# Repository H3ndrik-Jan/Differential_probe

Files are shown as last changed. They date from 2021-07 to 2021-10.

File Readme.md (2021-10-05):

# Battery powered differential oscilloscope probe
This repository contains schematics and design files, simulations and measurement results of the probe.
More details: https://hackaday.io/project/181410-battery-powered-differential-probe
# Pictures
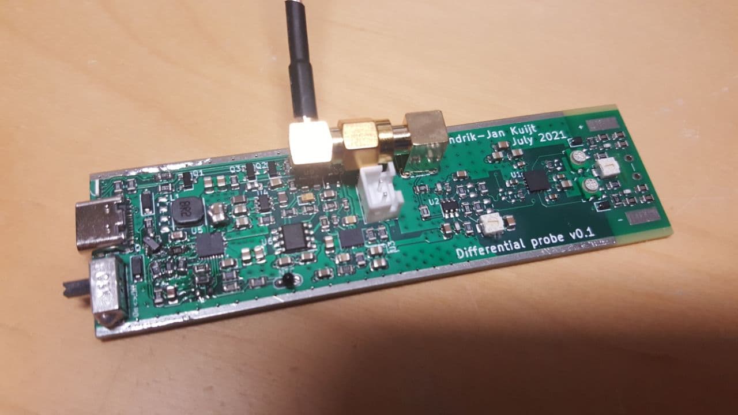
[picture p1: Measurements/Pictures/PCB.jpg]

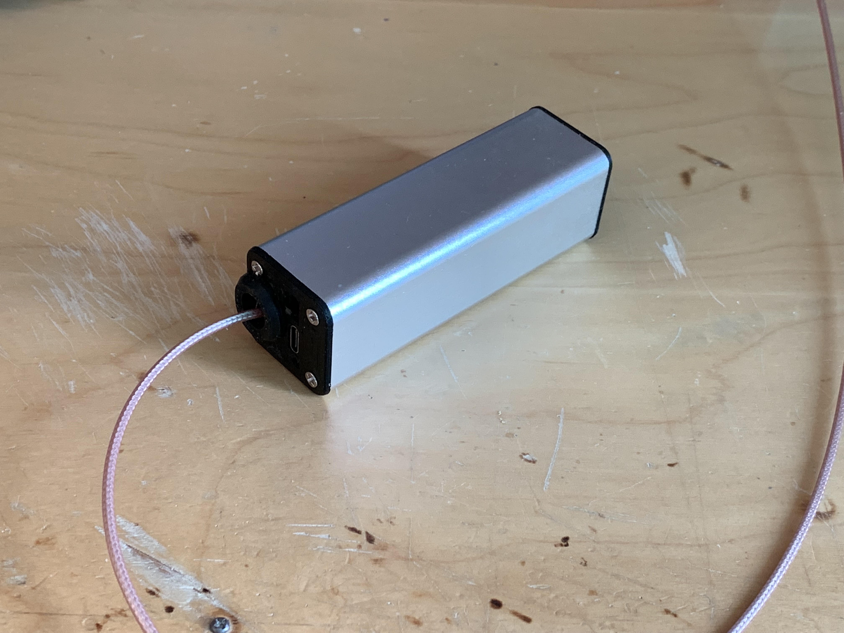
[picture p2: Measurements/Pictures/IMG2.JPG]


# 1Hz-950KHz transfer + THD:
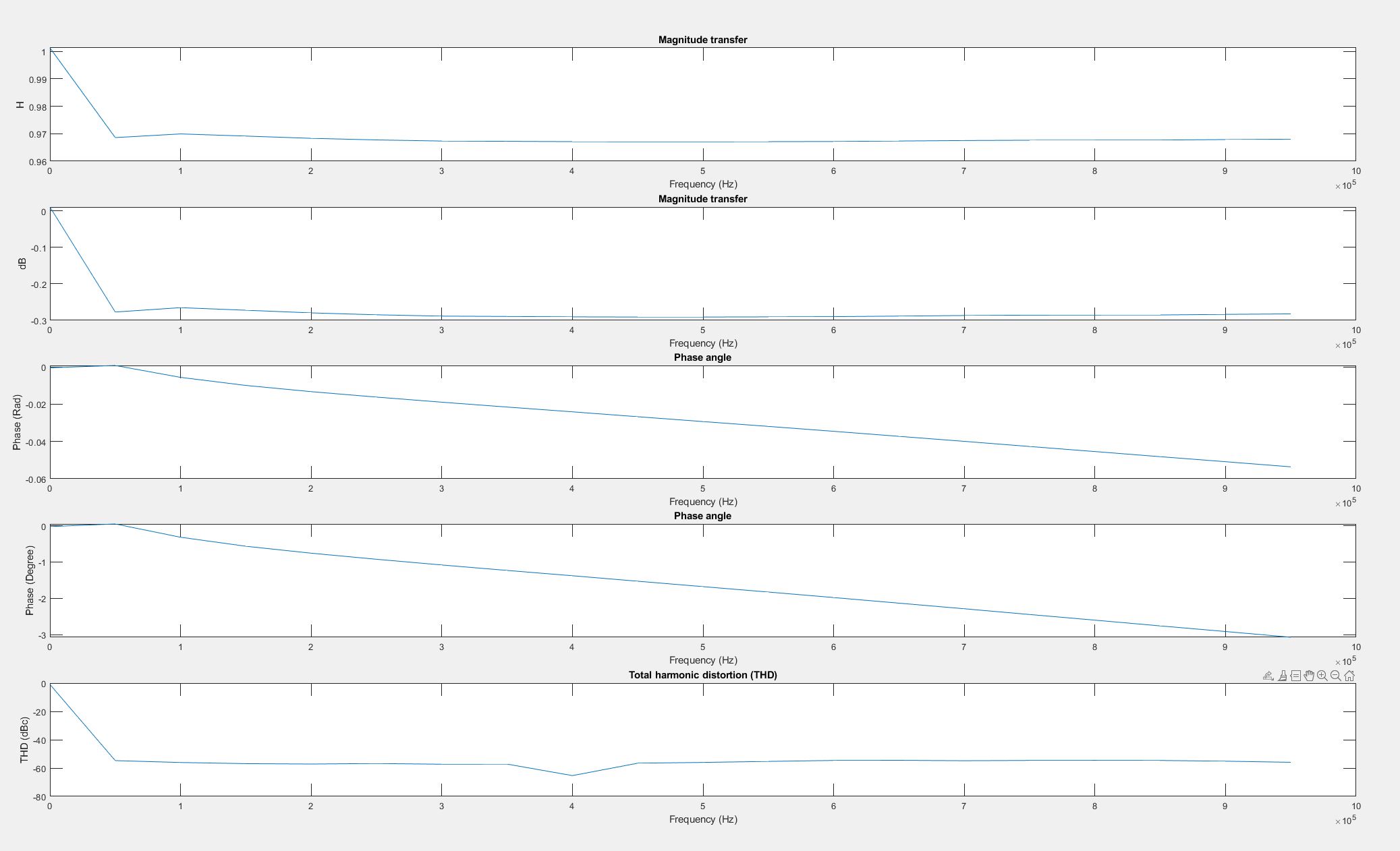
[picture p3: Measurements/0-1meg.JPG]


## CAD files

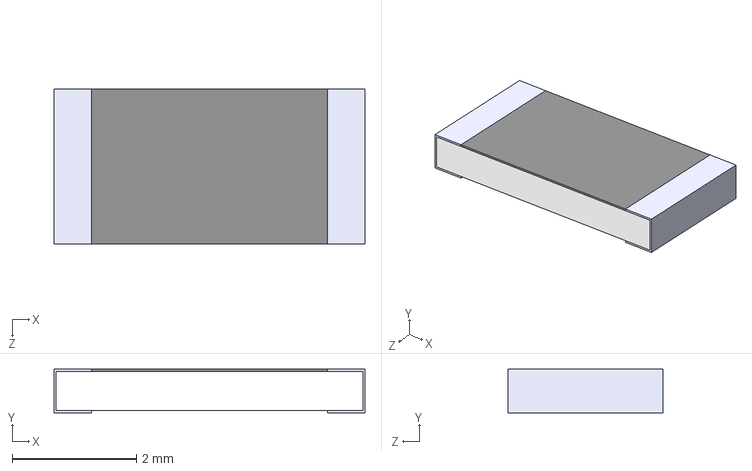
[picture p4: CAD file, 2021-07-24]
Diffprobe/3313J-1-103E.step
5.00 x 0.7 x 2.50 mm

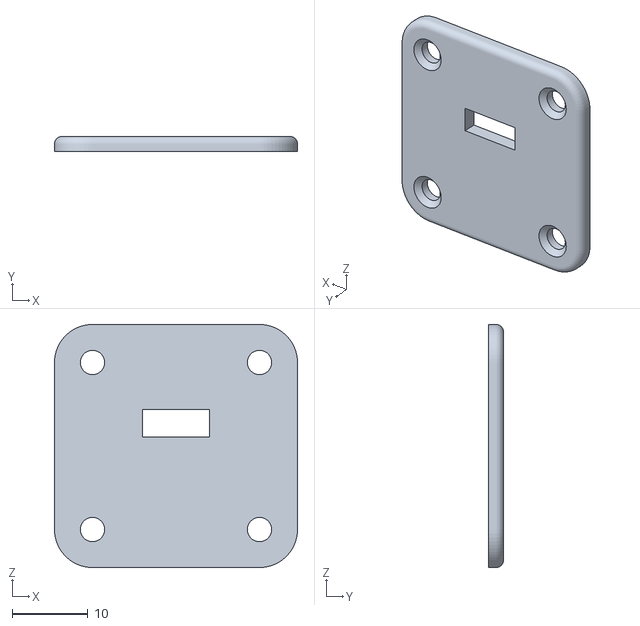
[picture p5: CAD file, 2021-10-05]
frontplate.stl
32.0 x 2.00 x 32.0

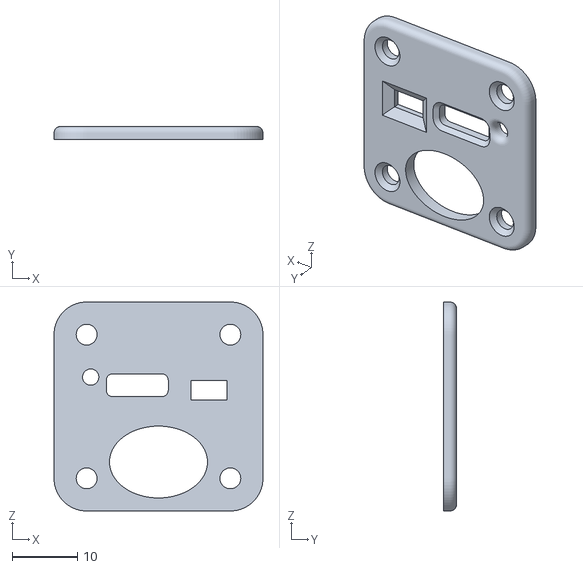
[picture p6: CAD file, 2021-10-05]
chargeplate.stl
32.0 x 2.00 x 32.0

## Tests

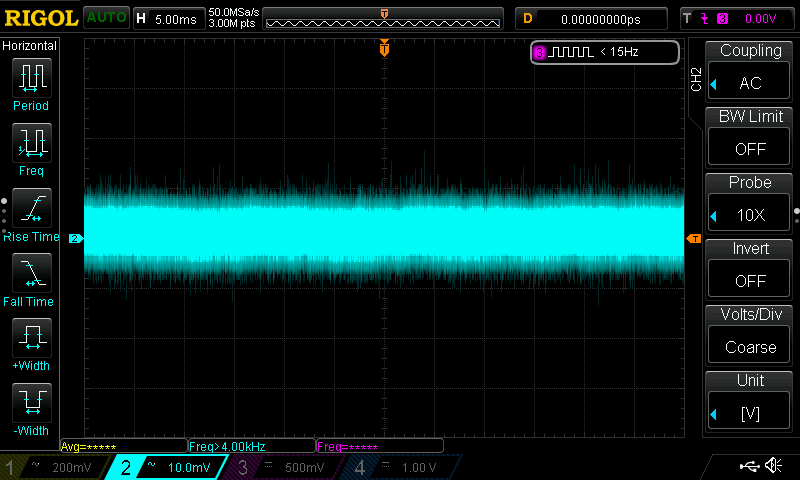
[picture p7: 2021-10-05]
Measurements/V+V-ripple5ms.png

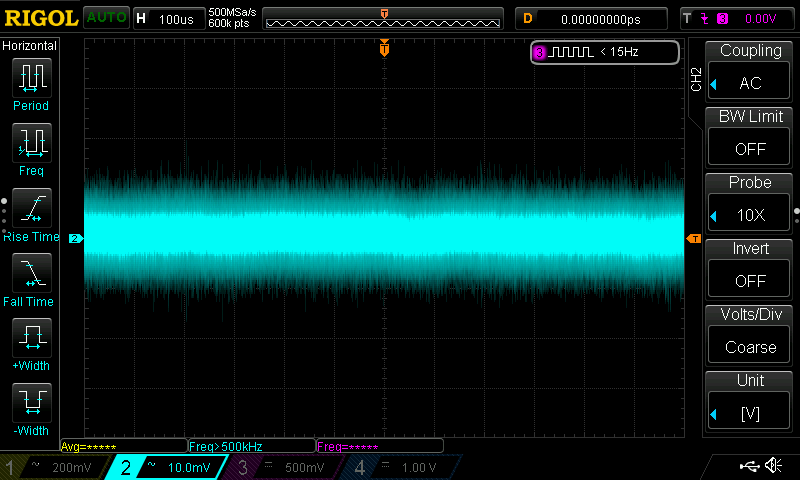
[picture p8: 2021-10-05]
Measurements/V+V-ripple100us.png

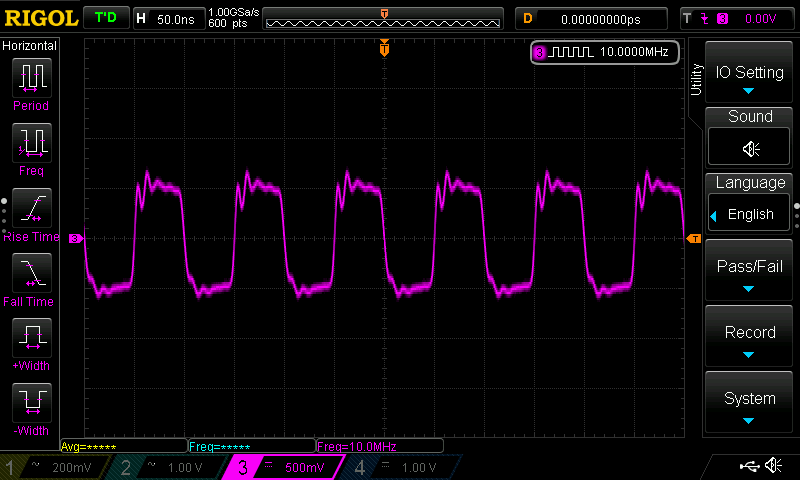
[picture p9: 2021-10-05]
Measurements/sqr10meg.png

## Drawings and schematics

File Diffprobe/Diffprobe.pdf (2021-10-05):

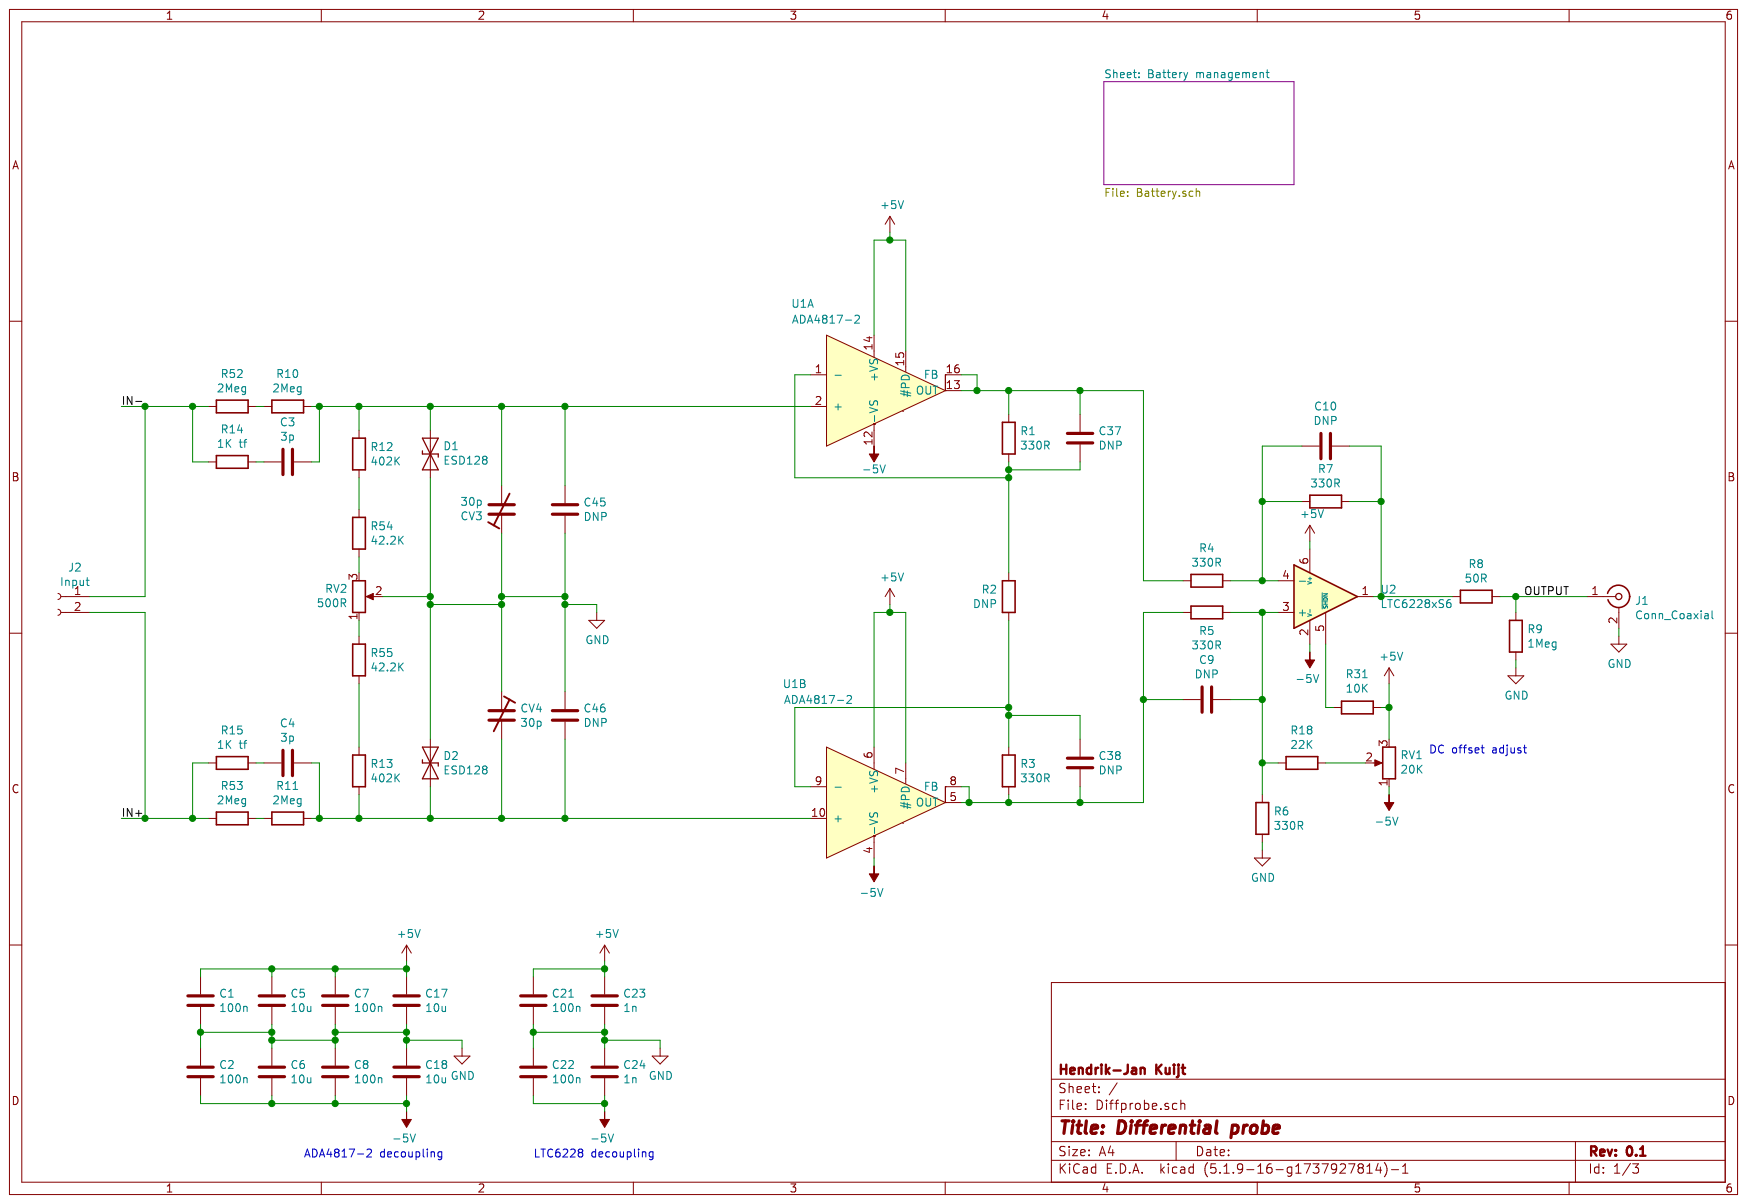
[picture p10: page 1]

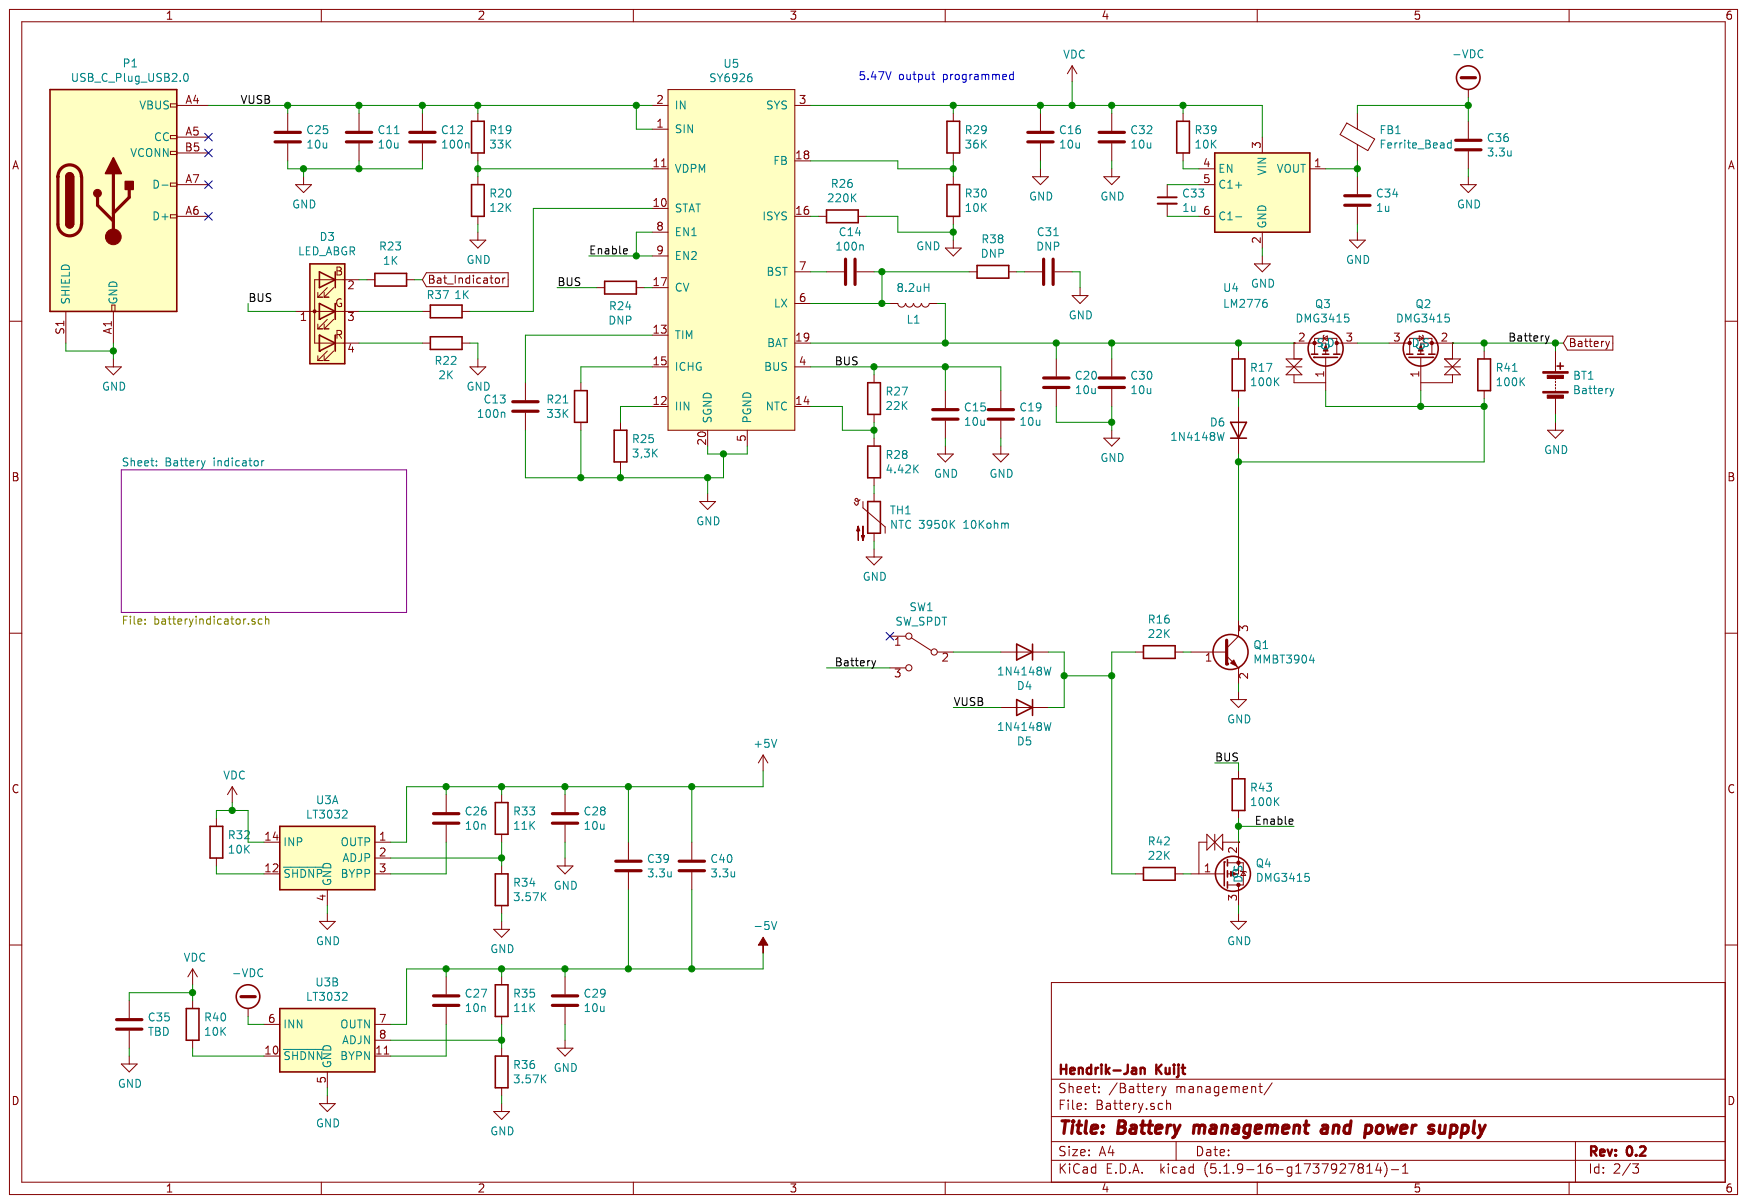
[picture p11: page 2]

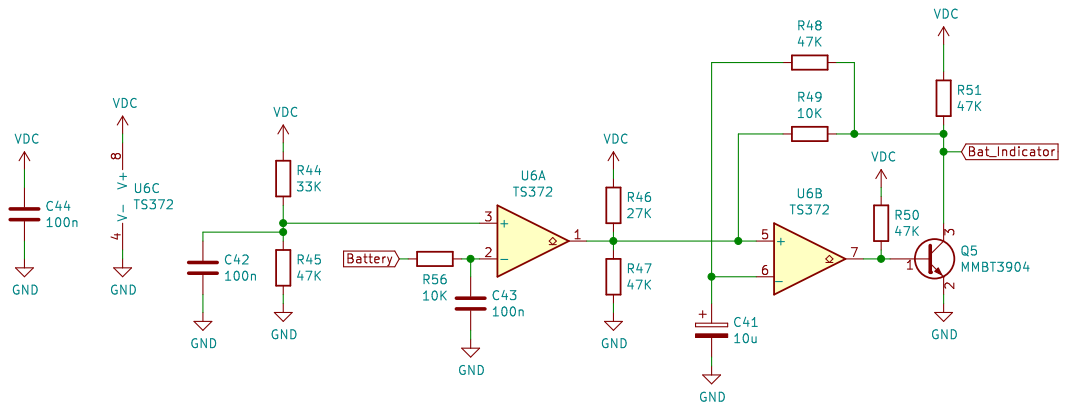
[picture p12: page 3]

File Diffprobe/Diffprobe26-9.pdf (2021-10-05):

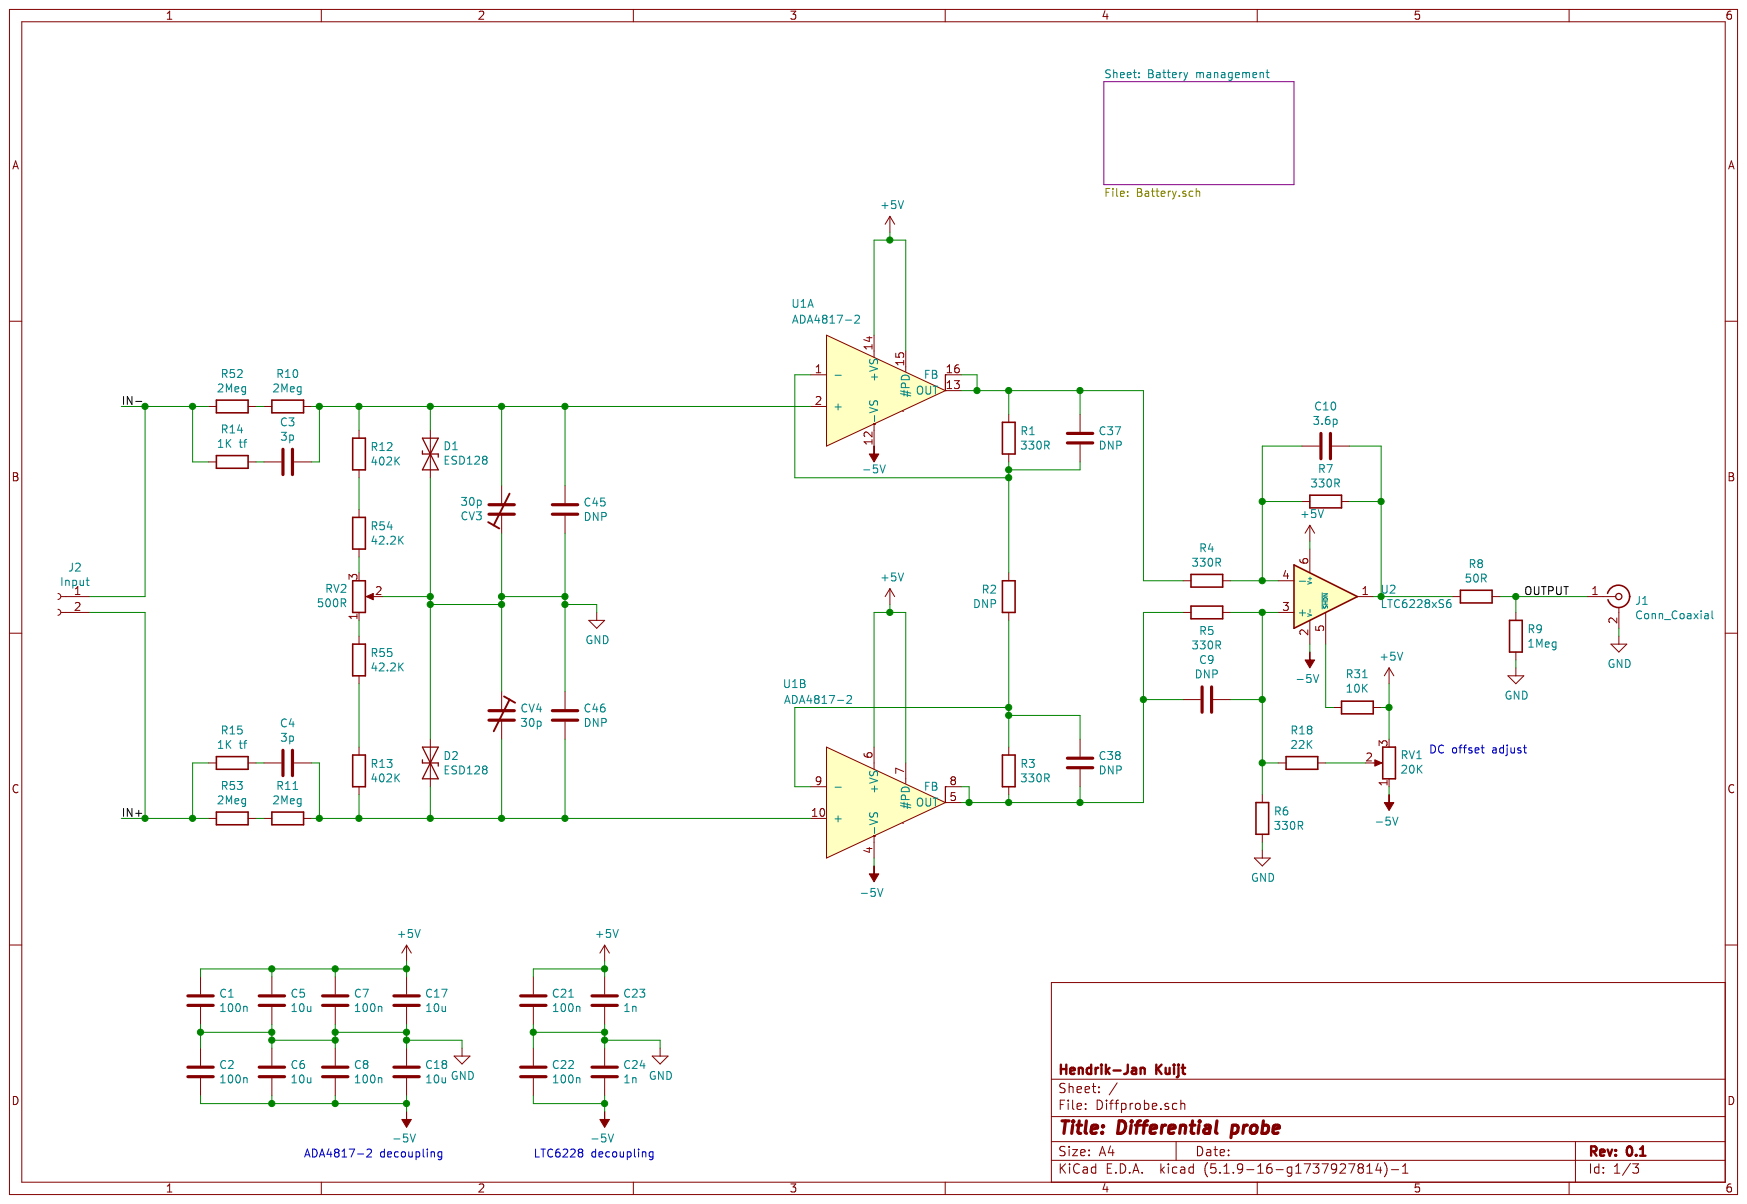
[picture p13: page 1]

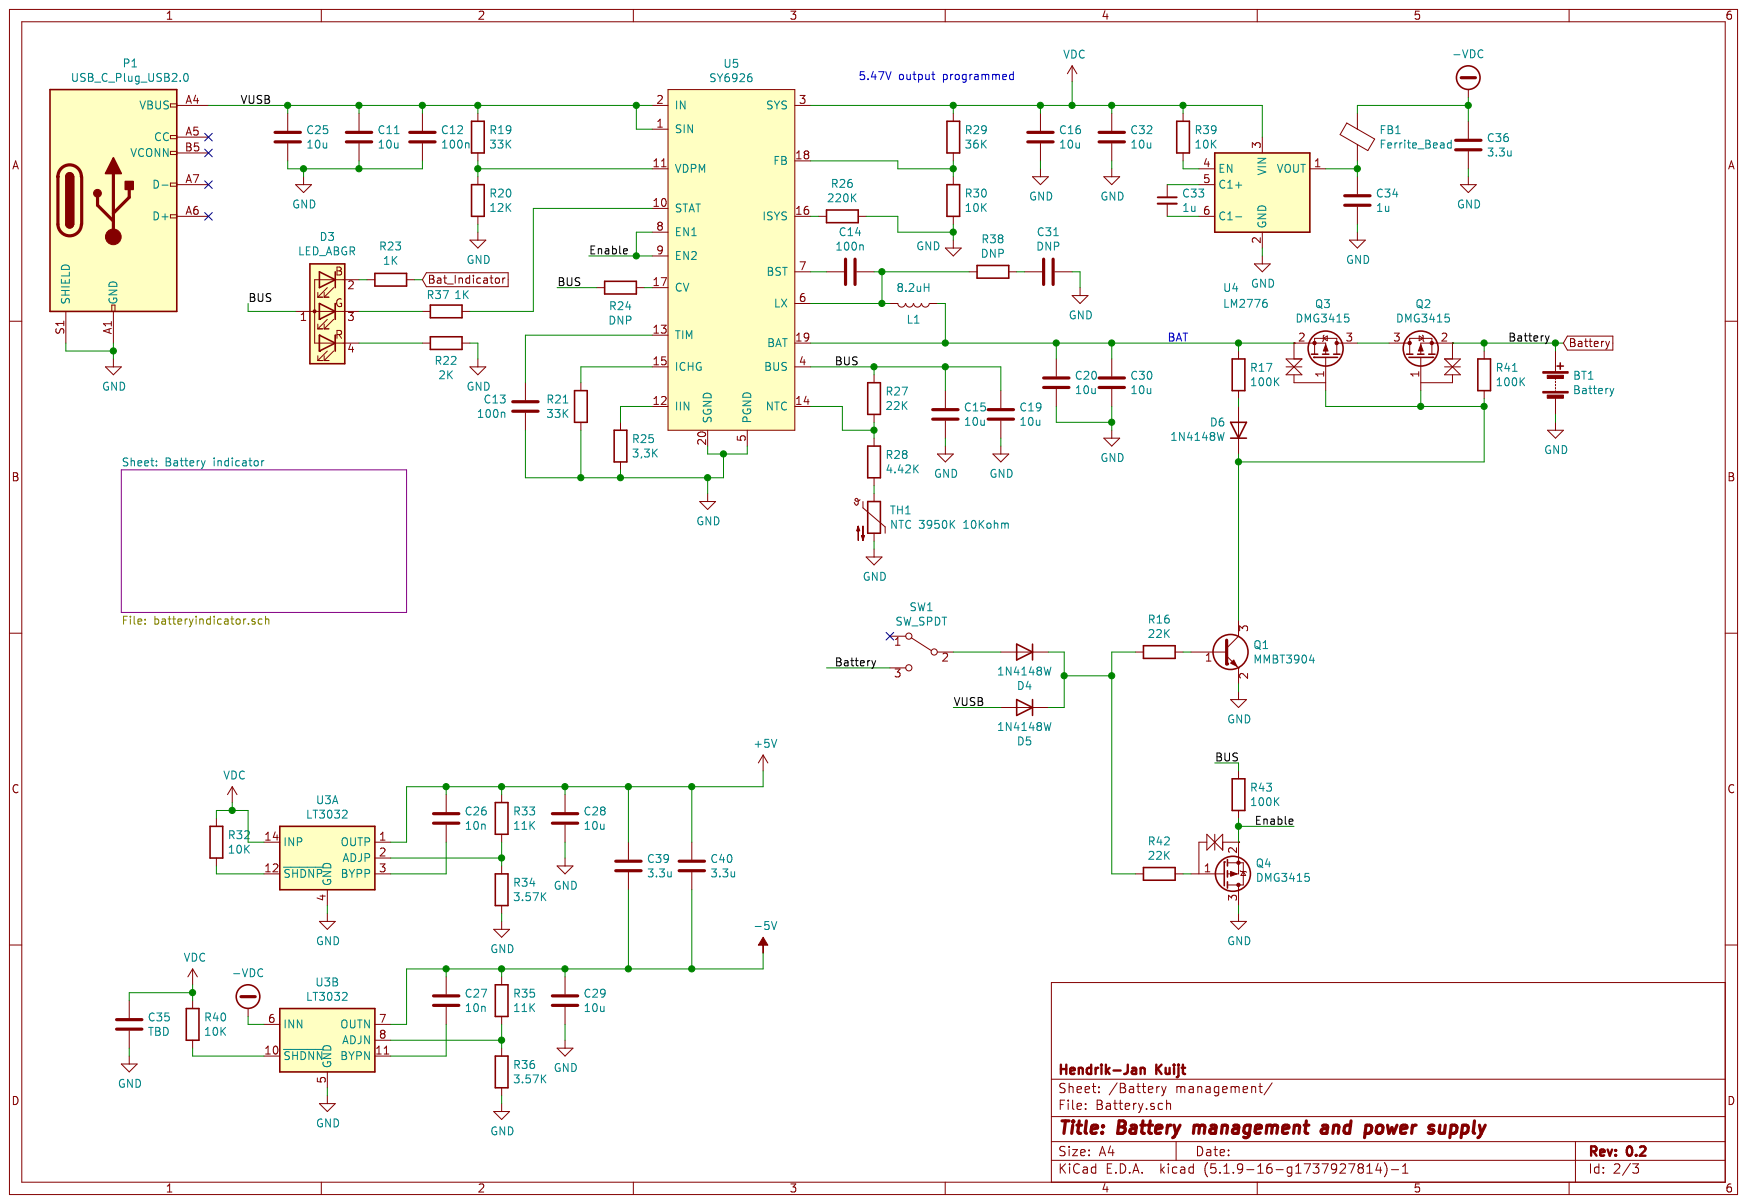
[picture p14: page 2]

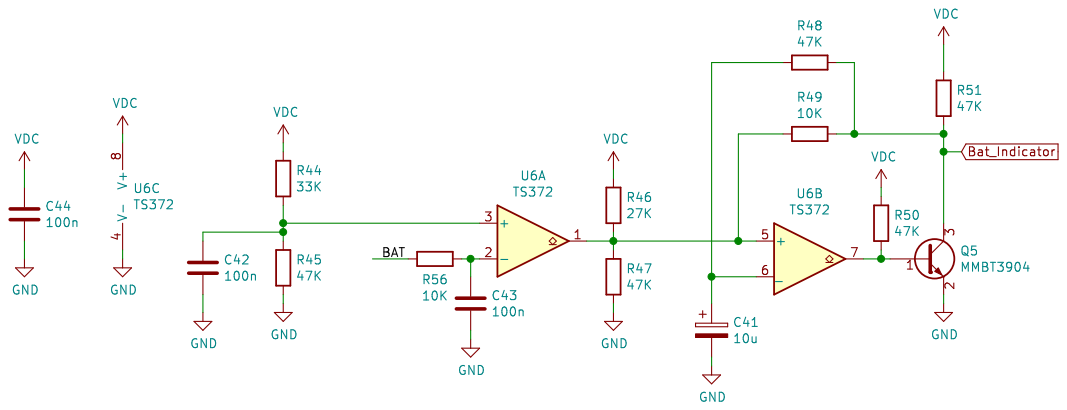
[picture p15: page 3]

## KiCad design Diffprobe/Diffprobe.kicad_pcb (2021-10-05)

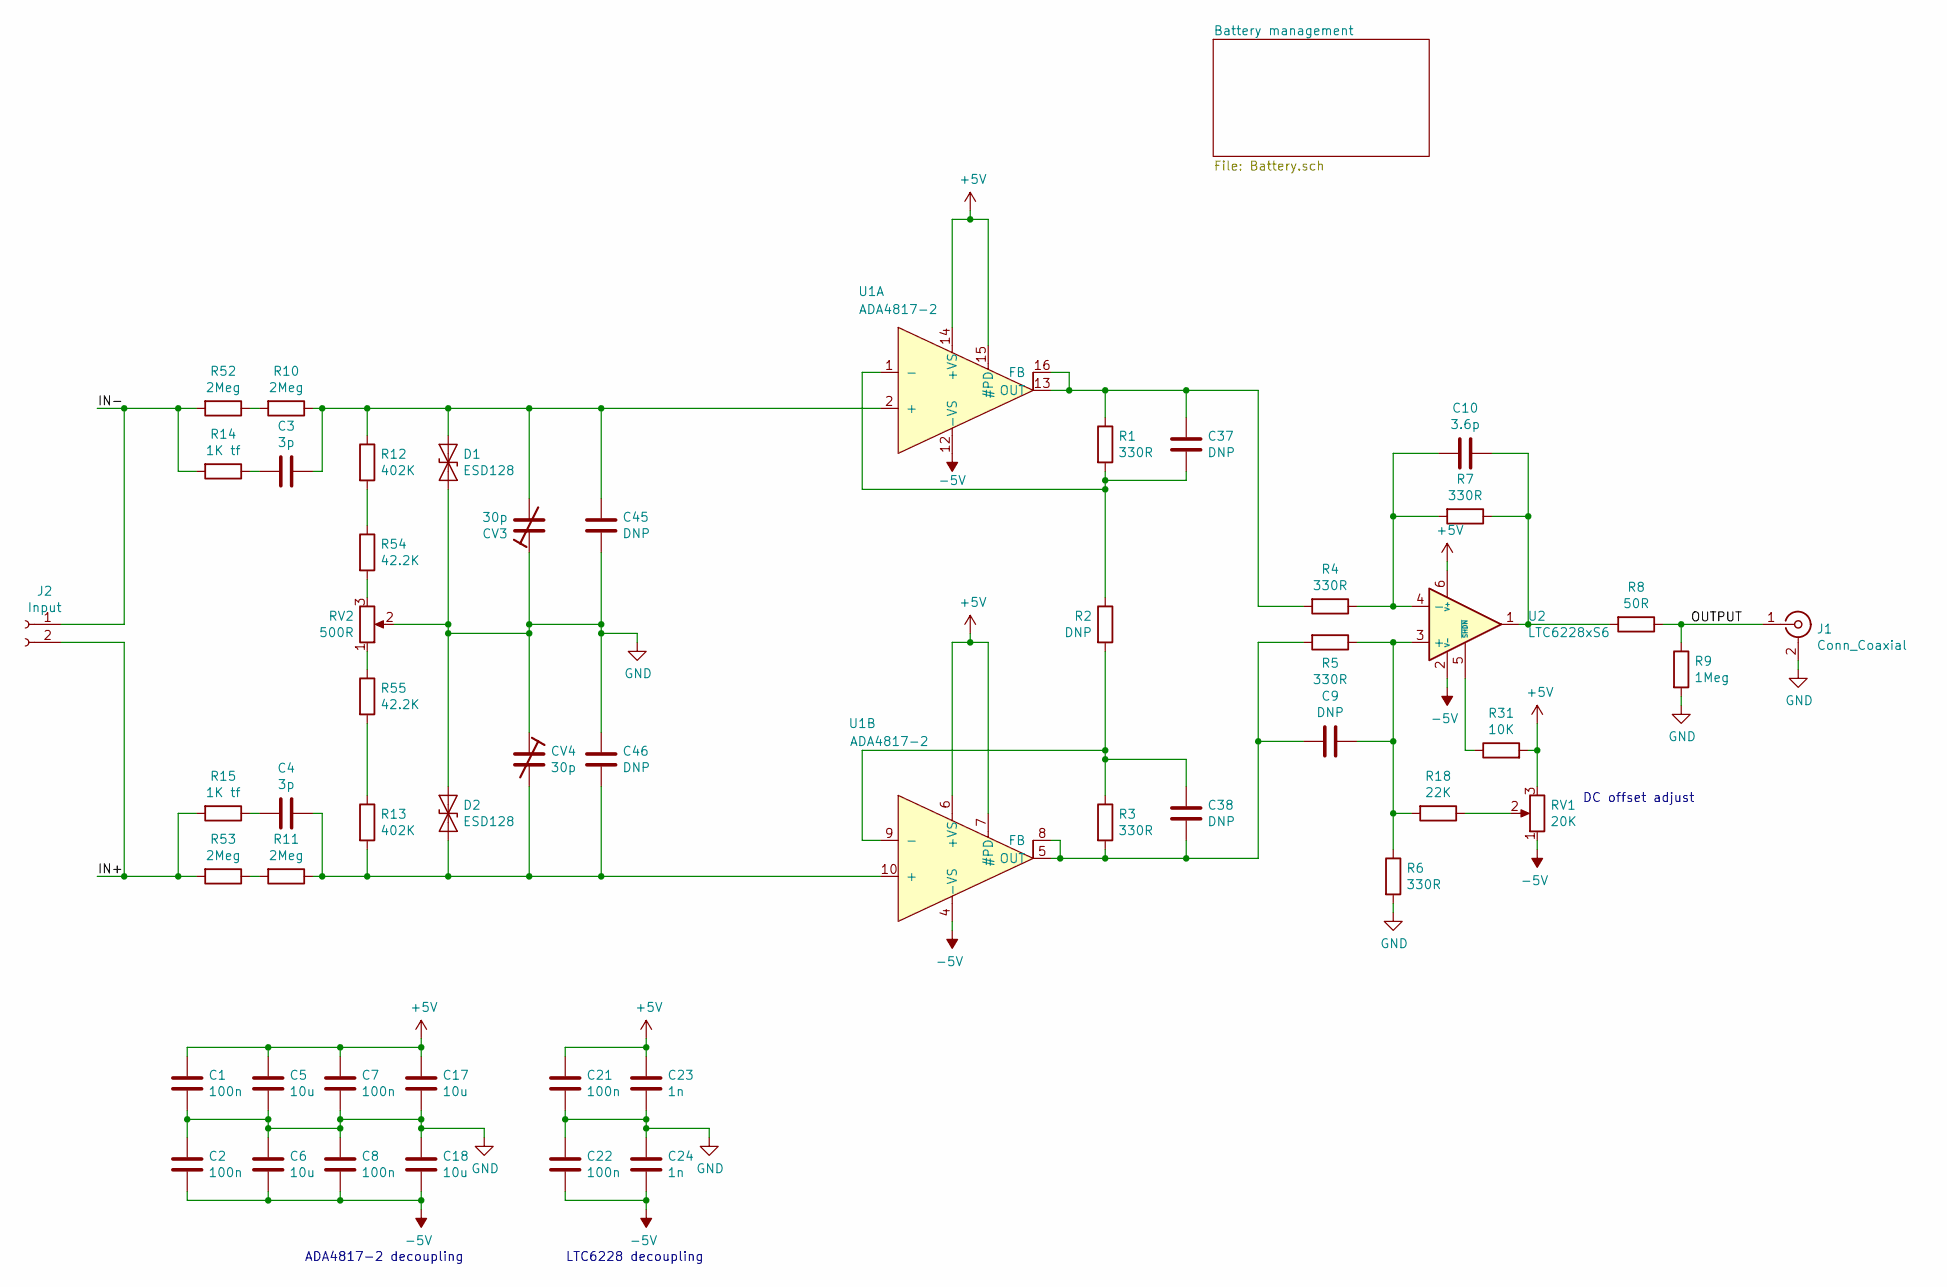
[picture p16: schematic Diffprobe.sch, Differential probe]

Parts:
C1, C2, C7, C22: 100n; C_0603_1608Metric
C3, C4: 3p; C_0603_1608Metric; LCSC C527036
C5, C6, C17, C18: 10u; C_0805_2012Metric; LCSC C15850
C8, C21: 100n; C_0805_2012Metric
C9: DNP; C_0805_2012Metric
C10: 3.6p; C_0805_2012Metric
C23, C24: 1n; C_0603_1608Metric; LCSC C106246
C37, C38: DNP; R_0603_1608Metric
C45, C46: DNP; C_0603_1608Metric
CV3, CV4: 30p; C_Trimmer_Murata_TZC3
D1, D2: ESD128; D_SOD-323; LCSC C151993
J1: Conn_Coaxial; SMA_Wurth_60312002114503_Vertical
J2: Input; probepads
R1, R3: 330R; R_0603_1608Metric; LCSC C328393
R2: DNP; R_0603_1608Metric
R4, R5, R6, R7: 330R; R_0805_2012Metric; LCSC C328393
R8: 50R; R_0805_2012Metric; LCSC C164002
R9: 1Meg; R_0805_2012Metric; LCSC C107700
R10, R11, R52, R53: 2Meg; R_0805_2012Metric; LCSC C306157
R12, R13: 402K; R_0805_2012Metric; LCSC C706240
R14, R15: 1K tf; R_0805_2012Metric
R18: 22K; R_0805_2012Metric; LCSC C114565
R31: 10K; R_0603_1608Metric
R54, R55: 42.2K; R_0805_2012Metric; LCSC C706241
RV1: 20K; TRIM_3313J-1-103E
RV2: 500R; TRIM_3313J-1-103E
U1: ADA4817-2; LFCSP-16-1EP_4x4mm_P0.65mm_EP2.4x2.4mm
U2: LTC6228xS6; TSOT-23-6

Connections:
+5V: C1.1, C5.1, C7.1, C17.1, C21.1, C23.1, R31.2, RV1.3, U1.6 (+VS), U1.7 (#PD), U1.14 (+VS), U1.15 (#PD), U2.6 (V+); also elsewhere on the board
-5V: C2.2, C6.2, C8.2, C18.2, C22.2, C24.2, RV1.1, U1.4 (-VS), U1.12 (-VS), U2.2 (V-); also elsewhere on the board
/IN+: J2.2, R15.2, R53.2
/IN-: J2.1, R14.2, R52.2
/OUTPUT: J1.1 (In), R8.1, R9.1
GND: C1.2, C2.1, C5.2, C6.1, C7.2, C8.1, C17.2, C18.1, C21.2, C22.1, C23.2, C24.1, C45.2, C46.1, CV3.1, CV4.1, D1.1 (A1), D2.1 (A1), J1.2 (Ext), R6.2, R9.2, RV2.2; also elsewhere on the board
unnamed: C3.1, C45.1, CV3.2, D1.2 (A2), R10.1, R12.1, U1.2 (+)
unnamed: C3.2, R14.1
unnamed: C4.1, C46.2, CV4.2, D2.2 (A2), R11.1, R13.2, U1.10 (+)
unnamed: C4.2, R15.1
unnamed: C9.1, R5.1, R6.1, R18.2, U2.3 (+)
unnamed: C10.1, R7.1, R8.2, U2.1
unnamed: C10.2, R4.1, R7.2, U2.4 (-)
unnamed: C37.1, R1.1, R4.2, U1.13 (OUT), U1.16 (FB)
unnamed: C37.2, R1.2, R2.1, U1.1 (-)
unnamed: C38.1, R2.2, R3.1, U1.9 (-)
unnamed: C9.2, C38.2, R3.2, R5.2, U1.5 (OUT), U1.8 (FB)
unnamed: R10.2, R52.1
unnamed: R11.2, R53.1
unnamed: R12.2, R54.1
unnamed: R13.1, R55.2
unnamed: R18.1, RV1.2
unnamed: R31.1, U2.5 (~SHDN)
unnamed: R54.2, RV2.3
unnamed: R55.1, RV2.1

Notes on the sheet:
LTC6228 decoupling
ADA4817-2 decoupling
DC offset adjust

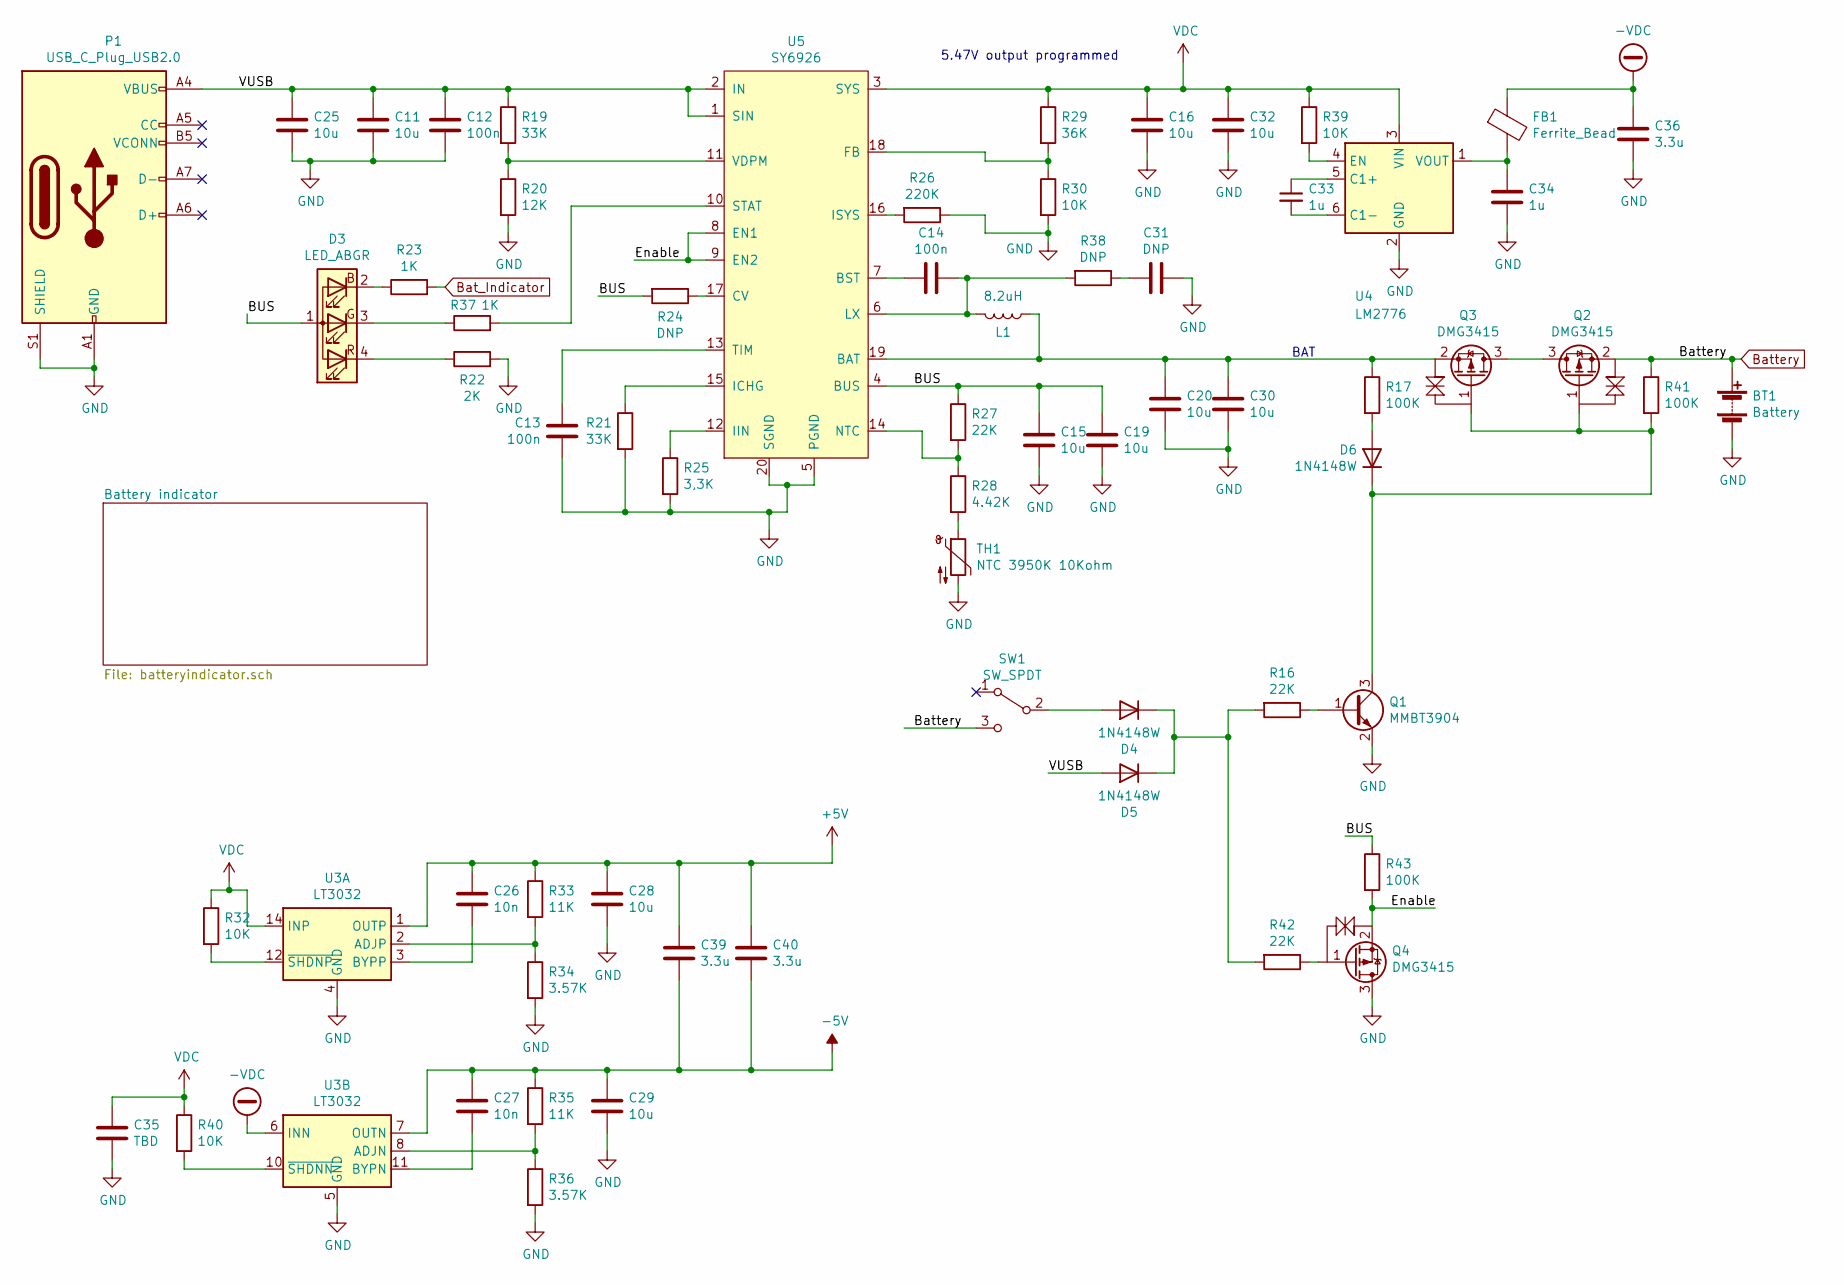
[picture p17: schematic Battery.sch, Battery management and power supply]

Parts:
BT1: Battery; JST_XH_B2B-XH-A_1x02_P2.50mm_Vertical
C11, C15, C16, C19, C20, C25, C28, C29, C30, C32: 10u; C_0805_2012Metric; LCSC C15850
C12, C13, C14: 100n; C_0805_2012Metric
C26, C27: 10n; C_0805_2012Metric
C31: DNP; C_0805_2012Metric
C33, C34: 1u; C_0805_2012Metric; LCSC C282733
C35: TBD; C_0805_2012Metric
C36, C39, C40: 3.3u; C_0805_2012Metric; LCSC C38332
D3: LED_ABGR; MHS110_RGB; LCSC C397052
D4, D5, D6: 1N4148W; D_SOD-123
FB1: Ferrite_Bead; L_0805_2012Metric
L1: 8.2uH; L_Taiyo-Yuden_MD-5050; LCSC C167935
P1: USB_C_Plug_USB2.0; USB_C_Receptacle_XKB_U262-16XN-4BVC11; LCSC C393939
Q1: MMBT3904; SOT-23
Q2, Q3, Q4: DMG3415; SOT-23
R16, R27, R42: 22K; R_0805_2012Metric; LCSC C114565
R17, R41, R43: 100K; R_0805_2012Metric
R19, R21: 33K; R_0805_2012Metric; LCSC C147826
R20: 12K; R_0805_2012Metric
R22: 2K; R_0805_2012Metric
R23: 1K; R_0805_2012Metric
R24, R38: DNP; R_0805_2012Metric
R25: 3,3K; R_0805_2012Metric
R26: 220K; R_0805_2012Metric
R28: 4.42K; R_0805_2012Metric
R29: 36K; R_0805_2012Metric; LCSC C168444
R30, R39: 10K; R_0805_2012Metric
R32, R40: 10K; R_0603_1608Metric
R33, R35: 11K; R_0805_2012Metric
R34, R36: 3.57K; R_0805_2012Metric; LCSC C245322
R37: 1K; R_0805_2012Metric; LCSC C880597
SW1: SW_SPDT; SW_CuK_OS102011MA1QN1_SPDT_Angled; LCSC C226259
TH1: NTC 3950K 10Kohm; TestPoint_2Pads_Pitch2.54mm_Drill0.8mm; LCSC C123378
U3: LT3032; Linear_DE14MA; LCSC C514419
U4: LM2776; SOT-23-6; LCSC C69527
U5: SY6926; QFN-20_L4.0-W4.0-P0.45-BL; LCSC C180877

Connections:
+5V: C26.1, C28.1, C39.1, C40.1, R33.1, U3.1 (OUTP); also elsewhere on the board
-5V: C27.1, C29.1, C39.2, C40.2, R35.1, U3.7 (OUTN); also elsewhere on the board
-VDC: C36.1, FB1.1, U3.6 (INN), U3.9 (INN)
/Battery management/BUS: C15.1, C19.1, D3.1 (A), R24.2, R27.1, R43.1, U5.4 (BUS)
/Battery management/Enable: Q4.2, R43.2, U5.8 (EN1), U5.9 (EN2)
/Battery management/VUSB: C11.1, C12.1, C25.1, D5.2 (A), P1.A4 (VBUS), P1.A9 (VBUS), P1.B4 (VBUS), P1.B9 (VBUS), R19.1, U5.1 (SIN), U5.2 (IN)
Bat_Indicator: R23.2; also elsewhere on the board
GND: BT1.2 (-), C11.2, C12.2, C13.2, C15.2, C16.2, C19.2, C20.2, C25.2, C28.2, C29.2, C30.2, C31.1, C32.2, C34.2, C35.2, C36.2, P1.A1 (GND), P1.A12 (GND), P1.B1 (GND), P1.B12 (GND), P1.S1 (SHIELD), Q1.2 (E), Q4.3, R20.2, R21.2, R22.2, R25.2, R26.1, R30.2, R34.2, R36.2, TH1.2, U3.4 (GND), U3.5 (GND), U4.2 (GND), U5.5 (PGND), U5.20 (SGND); also elsewhere on the board
unnamed: C13.1, U5.13 (TIM)
unnamed: C14.1, L1.2, R38.2, U5.6 (LX)
unnamed: C14.2, U5.7 (BST)
unnamed: C20.1, C30.1, L1.1, Q3.2, R17.1, U5.19 (BAT)
unnamed: C26.2, U3.3 (BYPP)
unnamed: C27.2, U3.11 (BYPN)
unnamed: C31.2, R38.1
unnamed: C33.1, U4.5 (C1+)
unnamed: C33.2, U4.6 (C1-)
unnamed: C34.1, FB1.2, U4.1 (VOUT)
unnamed: D3.2 (BK), R23.1
unnamed: D3.3 (GK), R37.1
unnamed: D3.4 (RK), R22.1
unnamed: D4.1 (K), D5.1 (K), R16.2, R42.2
unnamed: D4.2 (A), SW1.2 (B)
unnamed: D6.1 (K), Q1.3 (C), Q2.1, Q3.1, R41.2
unnamed: D6.2 (A), R17.2
unnamed: Q1.1 (B), R16.1
unnamed: Q2.3, Q3.3
unnamed: Q4.1, R42.1
unnamed: R19.2, R20.1, U5.11 (VDPM)
unnamed: R21.1, U5.15 (ICHG)
unnamed: R24.1, U5.17 (CV)
unnamed: R25.1, U5.12 (IIN)
unnamed: R26.2, U5.16 (ISYS)
unnamed: R27.2, R28.1, U5.14 (NTC)
unnamed: R28.2, TH1.1
unnamed: R29.2, R30.1, U5.18 (FB)
unnamed: R32.2, U3.12 (~SHDNP)
unnamed: R33.2, R34.1, U3.2 (ADJP)
unnamed: R35.2, R36.1, U3.8 (ADJN)
unnamed: R37.2, U5.10 (STAT)
unnamed: R39.2, U4.4 (EN)
unnamed: R40.2, U3.10 (~SHDNN)
VDC: C16.1, C32.1, C35.1, R29.1, R32.1, R39.1, R40.1, U3.14 (INP), U4.3 (VIN), U5.3 (SYS); also elsewhere on the board

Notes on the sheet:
5.47V output programmed
BAT

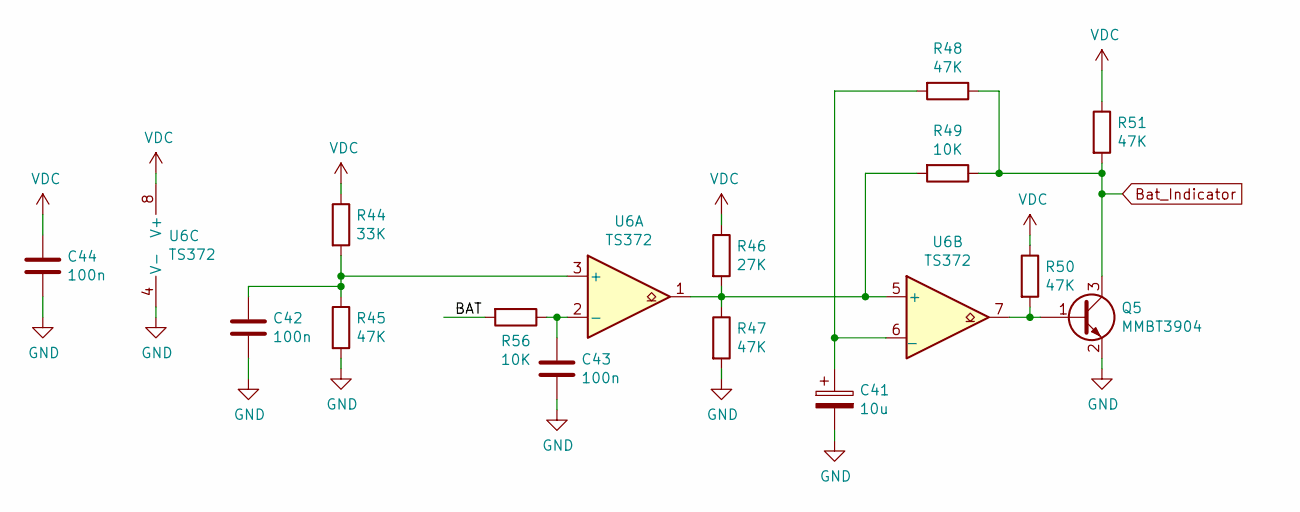
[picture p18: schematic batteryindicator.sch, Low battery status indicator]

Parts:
C41: 10u; CP_EIA-2012-15_AVX-P; LCSC C129234
C42, C43, C44: 100n; C_0805_2012Metric
Q5: MMBT3904; SOT-23
R44: 33K; R_0805_2012Metric; LCSC C147826
R45, R47, R48, R50, R51: 47K; R_0805_2012Metric; LCSC C126351
R46: 27K; R_0805_2012Metric; LCSC C352234
R49, R56: 10K; R_0805_2012Metric
U6: TS372; SO-8_3.9x4.9mm_P1.27mm; LCSC C71895

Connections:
Bat_Indicator: Q5.3 (C), R48.1, R49.1, R51.2; also elsewhere on the board
GND: C41.2, C42.2, C43.2, C44.2, Q5.2 (E), R45.2, R47.2, U6.4 (V-); also elsewhere on the board
unnamed: C41.1, R48.2, U6.6 (_)
unnamed: C42.1, R44.2, R45.1, U6.3 (+)
unnamed: Q5.1 (B), R50.2, U6.7
unnamed: R46.2, R47.1, R49.2, U6.1, U6.5 (+)
VDC: C44.1, R44.1, R46.1, R50.1, R51.1, U6.8 (V+); also elsewhere on the board

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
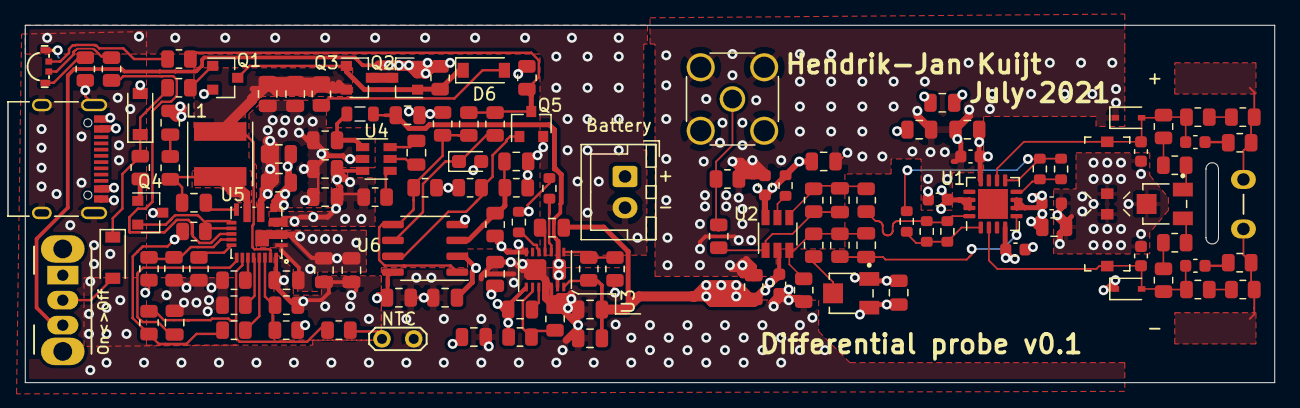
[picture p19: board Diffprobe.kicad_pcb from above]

Board: 4 copper layers, 100.0 x 28.6 mm, 130 parts (0 on the bottom side), 70 nets.

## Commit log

2021-07-13 two symbols added
    [Battery.sch, Diffprobe.kicad_pcb, Diffprobe.sch]
2021-07-15 differential amplifier + simulations + batterycharger added
    [Diffprobe.sch]
2021-07-24 more circuitry & simulation added
    [3313J-1-103E.step, Battery.sch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]
2021-10-05 readme, 3d files, measurements and more added
    [Battery.sch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]
